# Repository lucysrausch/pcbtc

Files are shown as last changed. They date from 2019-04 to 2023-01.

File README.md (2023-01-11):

#PCB based MIDI Tesla Coil

For documentation, please see (and like ;) my Hackaday project: https://hackaday.io/project/165112-pcbtc-gan-edition

For the mainboard, please use V1.6 to order the pcbs. Select the pcb thickness to be as thin as possible, eg. 1mm.
For the current design you also need the bottom pcb coil (https://github.com/lucysrausch/pcbtc/tree/master/hardware/gerber_coil_01) and the top pcb coil (https://github.com/lucysrausch/pcbtc/tree/master/hardware/gerber_coil_04).
For these pcbs, please use 1.6mm thickness or thicker (eg. 2mm).

Check out the interactive html BOM for easier assembly: https://github.com/lucysrausch/pcbtc/blob/master/hardware/kicad/bom/ibom.html

Known bugs (V1.5):
* Missing pulldown for gatedriver input of the flyback converter
This can cause problems when in DFU mode as the mosfet might switch on permanently, shortying VUSB (Fixed in V1.6)
* Missing input decoupling capacitors underneath the LMG5200.
Adding additional high-quality 100pF and 100nF ceramic capacitors on the bottom of the pcb improves performance drastically (Fixed in V1.6)
* Unknown problem causes GaN module to fail when touching the arcs with the finger or a screwdriver.
The reson for this is unknown so far. Maybe EMI, maybe bad layout. Just don't touch the arcs for too long for now. Discharges to air work reliably. (Maybe fixed in V1.6 thanks to suggestions from nikisalli)

Flash with dfu-util -d 0483:df11 -a 0 -s 0x8000000:leave -D build/pcbtcMIDI.bin

Midi stack based on:
https://github.com/keshikan/CureMIDI 

## USB-MIDI Interface (2IN/2OUT) for STM32 "CureMIDI"

### Author

(c) 2018 Keshikan ( [Website](http://www.keshikan.net/),  [Twitter](https://twitter.com/keshinomi_88pro) )

### License

* USB MIDI Class Driver: [CC BY 4.0](https://creativecommons.org/licenses/by/4.0/)
* STM32 CubeF0: BSD-3-Clause based.
* Other Codes, Hardware, Schematic: [GPLv3](https://www.gnu.org/licenses/gpl-3.0.html)

See also [LICENSE.md](./LICENSE.md)

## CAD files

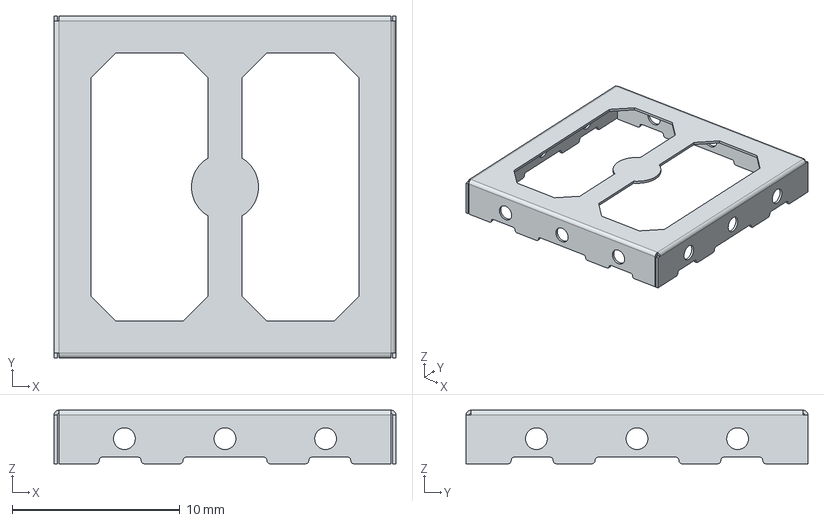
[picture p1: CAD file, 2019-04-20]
hardware/kicad/Download_STP_WE-SHC-36103205S (rev1).stp
20.4 x 20.4 x 3.20 mm

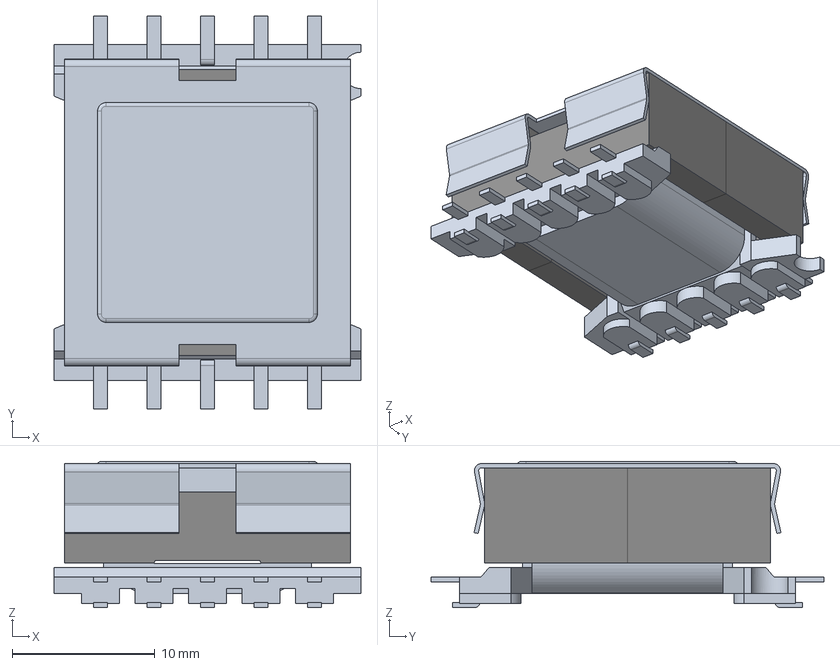
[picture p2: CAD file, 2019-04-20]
hardware/kicad/STEP-WE-FB-3751-EFD20-rev1.stp
21.5 x 27.5 x 10.2 mm

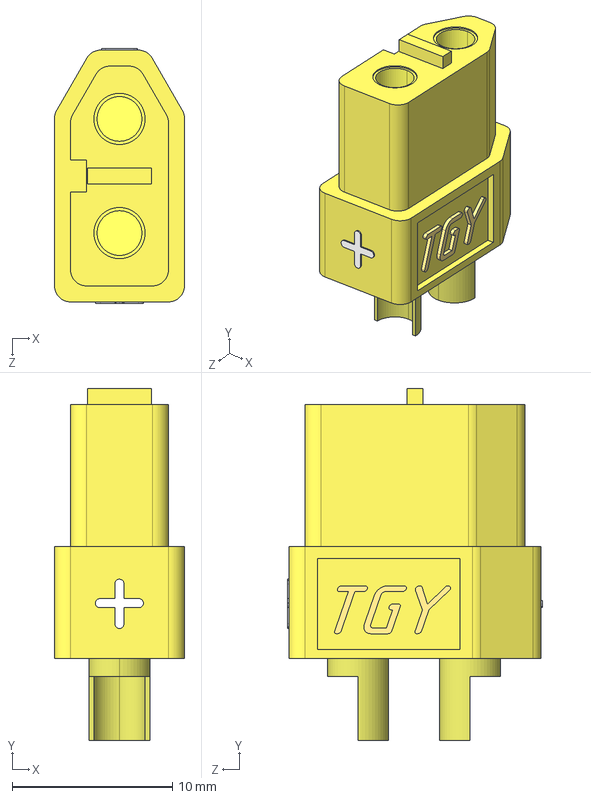
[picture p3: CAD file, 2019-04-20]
hardware/kicad/User Library-XT60.step
8.13 x 22.0 x 15.9 mm

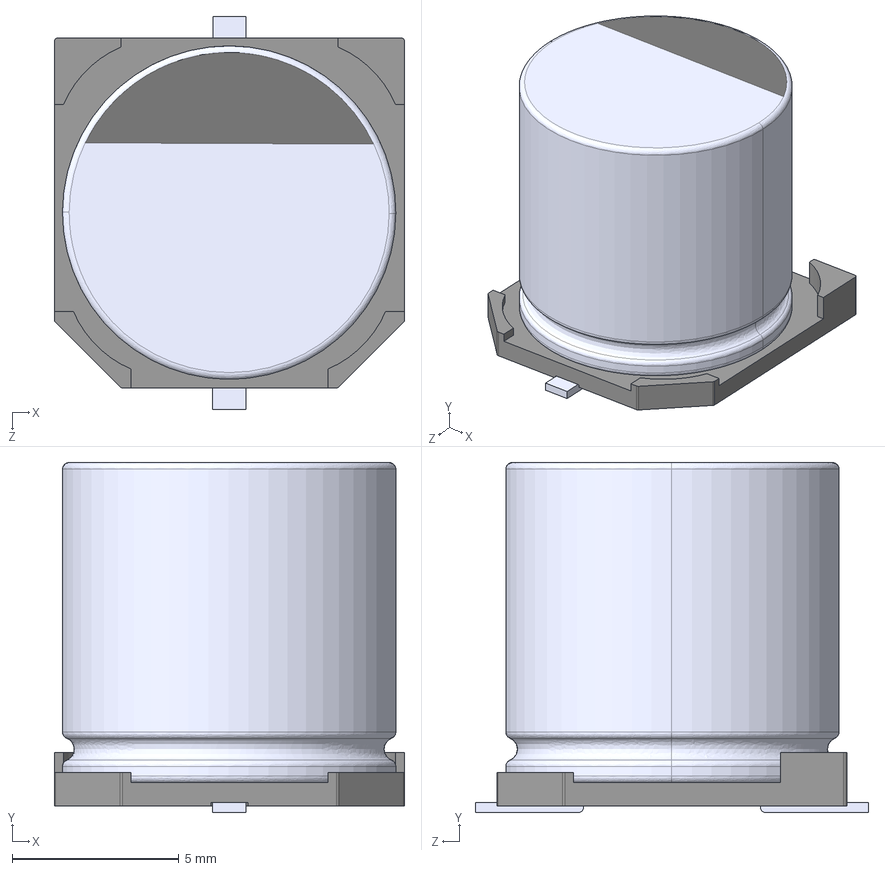
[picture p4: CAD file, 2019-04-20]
hardware/kicad/User Library-cap_10x10x10-1.STEP
10.5 x 10.5 x 11.8 mm
User Library-cap_10x10x10-1_can_10x10_1
User Library-cap_10x10x10-1_foot_cap_10x10_1 x 2
User Library-cap_10x10x10-1_alelcap_sm10x10_1

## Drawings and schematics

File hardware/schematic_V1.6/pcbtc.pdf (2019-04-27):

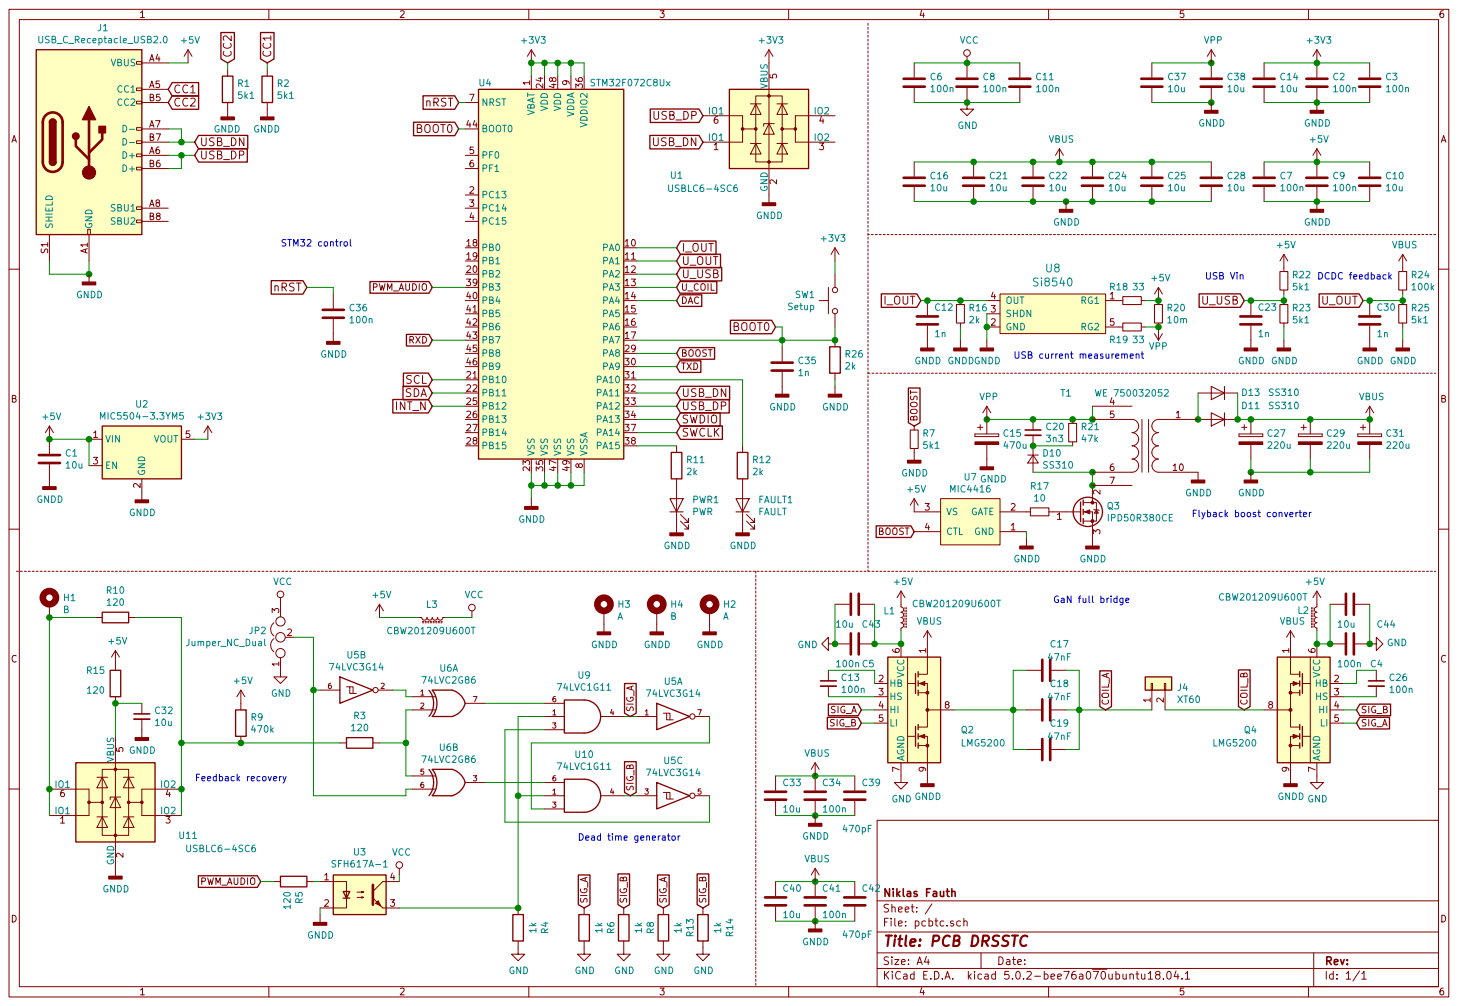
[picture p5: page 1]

9 VDDIO2 36 VSS 23 VSS 35 VSS 47 VSS 49 VSSA

2 EN 3 VOUT 5 U2 MIC5504-3.3YM5 +3V3 BOOST BOOST PWM_AUDIO

File: pcbtc.sch Sheet: / Niklas Fauth

Id: 1/1 Title: PCB DRSSTC

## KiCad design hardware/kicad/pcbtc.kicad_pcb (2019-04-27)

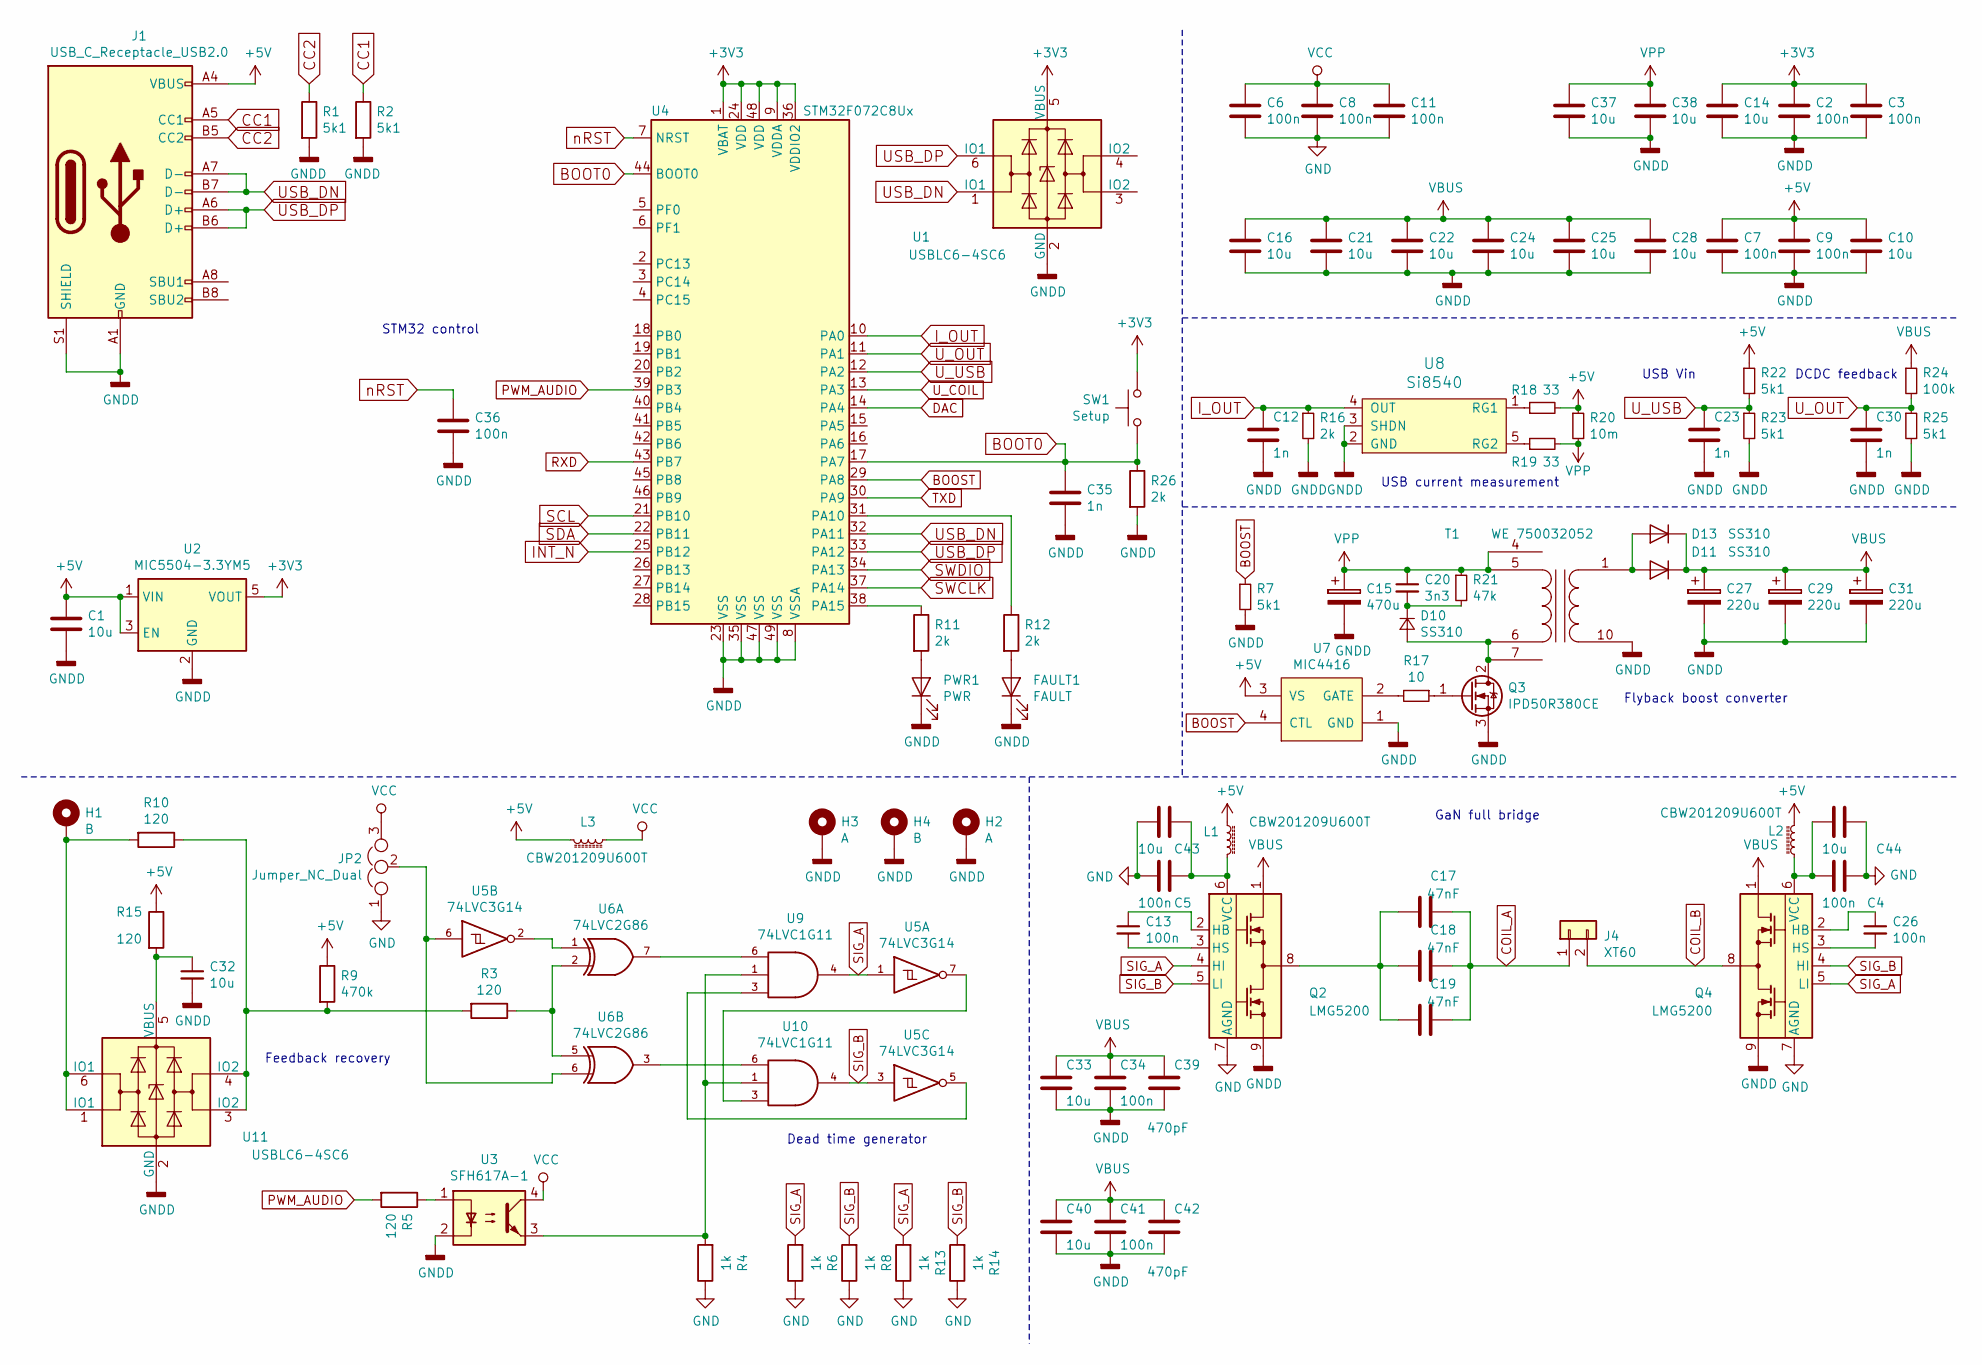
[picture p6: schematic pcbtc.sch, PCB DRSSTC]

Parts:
C1, C16, C21, C22, C24, C25, C28, C33, C37, C38, C40: 10u; C_1206_3216Metric
C2, C3, C4, C5, C6, C7, C8, C9, C11, C13, C26, C36: 100n; C_0603_1608Metric
C10, C14, C32, C43, C44: 10u; C_0603_1608Metric
C12, C23, C30, C35: 1n; C_0603_1608Metric
C15: 470u; C_Elec_10x10.2
C17, C18, C19: 47nF; C_Rect_L13.0mm_W6.5mm_P7.50mm_P10.00mm
C20: 3n3; C_1206_3216Metric
C27, C29, C31: 220u; C_Elec_10x10.2
C34, C41: 100n; C_1206_3216Metric
C39, C42: 470pF; C_1206_3216Metric
D10, D11, D13: SS310; D_SMA
FAULT1: FAULT; LED_0603_1608Metric
H1, H4: B; MountingHole_3.2mm_M3_Pad_Via
H2, H3: A; MountingHole_3.2mm_M3_Pad_Via
J1: USB_C_Receptacle_USB2.0; USB-C 16Pin
J4: XT60
JP2: Jumper_NC_Dual; SolderJumper-3_P1.3mm_Bridged12_RoundedPad1.0x1.5mm
L1, L2, L3: CBW201209U600T; L_0805_2012Metric
PWR1: PWR; LED_0603_1608Metric
Q2, Q4: LMG5200; Texas_MOF0009A
Q3: IPD50R380CE; TO-252-2
R1, R2: 5k1; C_0603_1608Metric
R3, R5, R10, R15: 120; R_0603_1608Metric
R4, R6, R8, R13, R14: 1k; R_0603_1608Metric
R7, R22, R23, R25: 5k1; R_0603_1608Metric
R9: 470k; R_0603_1608Metric
R11, R12, R16, R26: 2k; R_0603_1608Metric
R17: 10; R_0603_1608Metric
R18, R19: 33; R_0603_1608Metric
R20: 10m; R_1206_3216Metric
R21: 47k; R_1206_3216Metric
R24: 100k; R_0603_1608Metric
SW1: Setup; SW_SPST_EVQP7C
T1: WE 750032052; SignalCommunications-WE-FB3751_EFD20
U1, U11: USBLC6-4SC6; SOT-23-6
U2: MIC5504-3.3YM5; SOT-23-5
U3: SFH617A-1; DIP-4_W7.62mm_SMDSocket_SmallPads
U4: STM32F072C8Ux; QFN-48-1EP_7x7mm_P0.5mm_EP5.6x5.6mm
U5: 74LVC3G14; TSSOP-8_3x3mm_P0.65mm
U6: 74LVC2G86; TSSOP-8_3x3mm_P0.65mm
U7: MIC4416; SOT143-4P190_237X112L31X44N
U8: Si8540; SOT-23-5
U9, U10: 74LVC1G11; SOT-23-6

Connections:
+3V3: C2.1, C3.1, C14.1, SW1.1, U1.5 (VBUS), U2.5 (VOUT), U4.1 (VBAT), U4.9 (VDDA), U4.24 (VDD), U4.36 (VDDIO2), U4.48 (VDD)
+5V: C1.1, C7.1, C9.1, C10.1, J1.A4 (VBUS), J1.A9 (VBUS), J1.B4 (VBUS), J1.B9 (VBUS), L1.2, L2.2, L3.1, R9.1, R15.1, R18.2, R20.1, R22.1, U2.1 (VIN), U2.3 (EN), U7.3 (VS)
BOOST: R7.1, U4.29 (PA8), U7.4 (CTL)
BOOT0: C35.1, R26.1, SW1.2, U4.17 (PA7), U4.44 (BOOT0)
CC1: J1.A5 (CC1), R2.1
CC2: J1.B5 (CC2), R1.1
COIL_A: C17.1, C18.1, C19.1, J4.1
COIL_B: J4.2, Q4.8
DAC: U4.14 (PA4)
GND: C4.1, C5.2, C6.2, C8.2, C11.2, C43.2, C44.1, JP2.1, Q2.7 (AGND), Q4.7 (AGND), R4.1, R6.1, R8.1, R13.1, R14.1, U5.4 (GND), U6.4 (GND), U9.2 (GND), U10.2 (GND)
GNDD: C1.2, C2.2, C3.2, C7.2, C9.2, C10.2, C12.2, C14.2, C15.2, C16.2, C21.2, C22.2, C23.2, C24.2, C25.2, C27.2, C28.2, C29.2, C30.2, C31.2, C32.2, C33.2, C34.2, C35.2, C36.2, C37.2, C38.2, C39.2, C40.2, C41.2, C42.2, FAULT1.1 (K), H2.1, H3.1, H4.1, J1.A1 (GND), J1.A12 (GND), J1.B1 (GND), J1.B12 (GND), J1.S1 (SHIELD), PWR1.1 (K), Q2.9, Q3.3 (S), Q4.9, R1.2, R2.2, R7.2, R16.2, R23.2, R25.2, R26.2, T1.10 (SA), U1.2 (GND), U2.2 (GND), U3.2, U4.8 (VSSA), U4.23 (VSS), U4.35 (VSS), U4.47 (VSS), U4.49 (VSS), U7.1 (GND), U8.2 (GND), U8.3 (SHDN), U11.2 (GND)
INT_N: U4.25 (PB12)
I_OUT: C12.1, R16.1, U4.10 (PA0), U8.4 (OUT)
unnamed: C4.2, C44.2, L2.1, Q4.6 (VCC)
unnamed: C13.1, Q2.2 (HB)
unnamed: C13.2, Q2.3 (HS)
unnamed: C17.2, C18.2, C19.2, Q2.8
unnamed: C20.2, D10.1 (K), R21.2
unnamed: C26.1, Q4.2 (HB)
unnamed: C26.2, Q4.3 (HS)
unnamed: C32.1, R15.2, U11.5 (VBUS)
unnamed: C5.1, C43.1, L1.1, Q2.6 (VCC)
unnamed: D10.2 (A), Q3.2 (D), T1.6 (AB), T1.7
unnamed: D11.2 (A), D13.2 (A), T1.1 (SB)
unnamed: FAULT1.2 (A), R12.2
unnamed: H1.1, R10.2, U11.1 (IO1), U11.6 (IO1)
unnamed: JP2.2, U5.6, U6.6
unnamed: PWR1.2 (A), R11.2
unnamed: Q3.1 (G), R17.1
unnamed: R3.1, U6.2, U6.5
unnamed: R4.2, U3.3, U9.1, U10.1
unnamed: R5.1, U3.1
unnamed: R3.2, R9.2, R10.1, U11.3 (IO2), U11.4 (IO2)
unnamed: R11.1, U4.38 (PA15)
unnamed: R12.1, U4.31 (PA10)
unnamed: R17.2, U7.2 (GATE)
unnamed: R18.1, U8.1 (RG1)
unnamed: R19.1, U8.5 (RG2)
unnamed: U5.2, U6.1
unnamed: U5.5, U9.3
unnamed: U6.7, U9.6
unnamed: U5.7, U10.3
unnamed: U6.3, U10.6
PWM_AUDIO: R5.2, U4.39 (PB3)
RXD: U4.43 (PB7)
SCL: U4.21 (PB10)
SDA: U4.22 (PB11)
SIG_A: Q2.4 (HI), Q4.5 (LI), R6.2, R13.2, U5.1, U9.4
SIG_B: Q2.5 (LI), Q4.4 (HI), R8.2, R14.2, U5.3, U10.4
SWCLK: U4.37 (PA14)
SWDIO: U4.34 (PA13)
TXD: U4.30 (PA9)
USB_DN: J1.A7 (D-), J1.B7 (D-), U1.1 (IO1), U4.32 (PA11)
USB_DP: J1.A6 (D+), J1.B6 (D+), U1.6 (IO1), U4.33 (PA12)
U_COIL: U4.13 (PA3)
U_OUT: C30.1, R24.2, R25.1, U4.11 (PA1)
U_USB: C23.1, R22.2, R23.1, U4.12 (PA2)
VBUS: C16.1, C21.1, C22.1, C24.1, C25.1, C27.1, C28.1, C29.1, C31.1, C33.1, C34.1, C39.1, C40.1, C41.1, C42.1, D11.1 (K), D13.1 (K), Q2.1, Q4.1, R24.1
VCC: C6.1, C8.1, C11.1, JP2.3, L3.2, U3.4, U5.8 (VCC), U6.8 (VCC), U9.5 (VCC), U10.5 (VCC)
VPP: C15.1, C20.1, C37.1, C38.1, R19.2, R20.2, R21.1, T1.4, T1.5 (AA)
nRST: C36.1, U4.7 (NRST)

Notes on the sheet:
Feedback recovery
Dead time generator
GaN full bridge
Flyback boost converter
USB current measurement
DCDC feedback
USB Vin
STM32 control

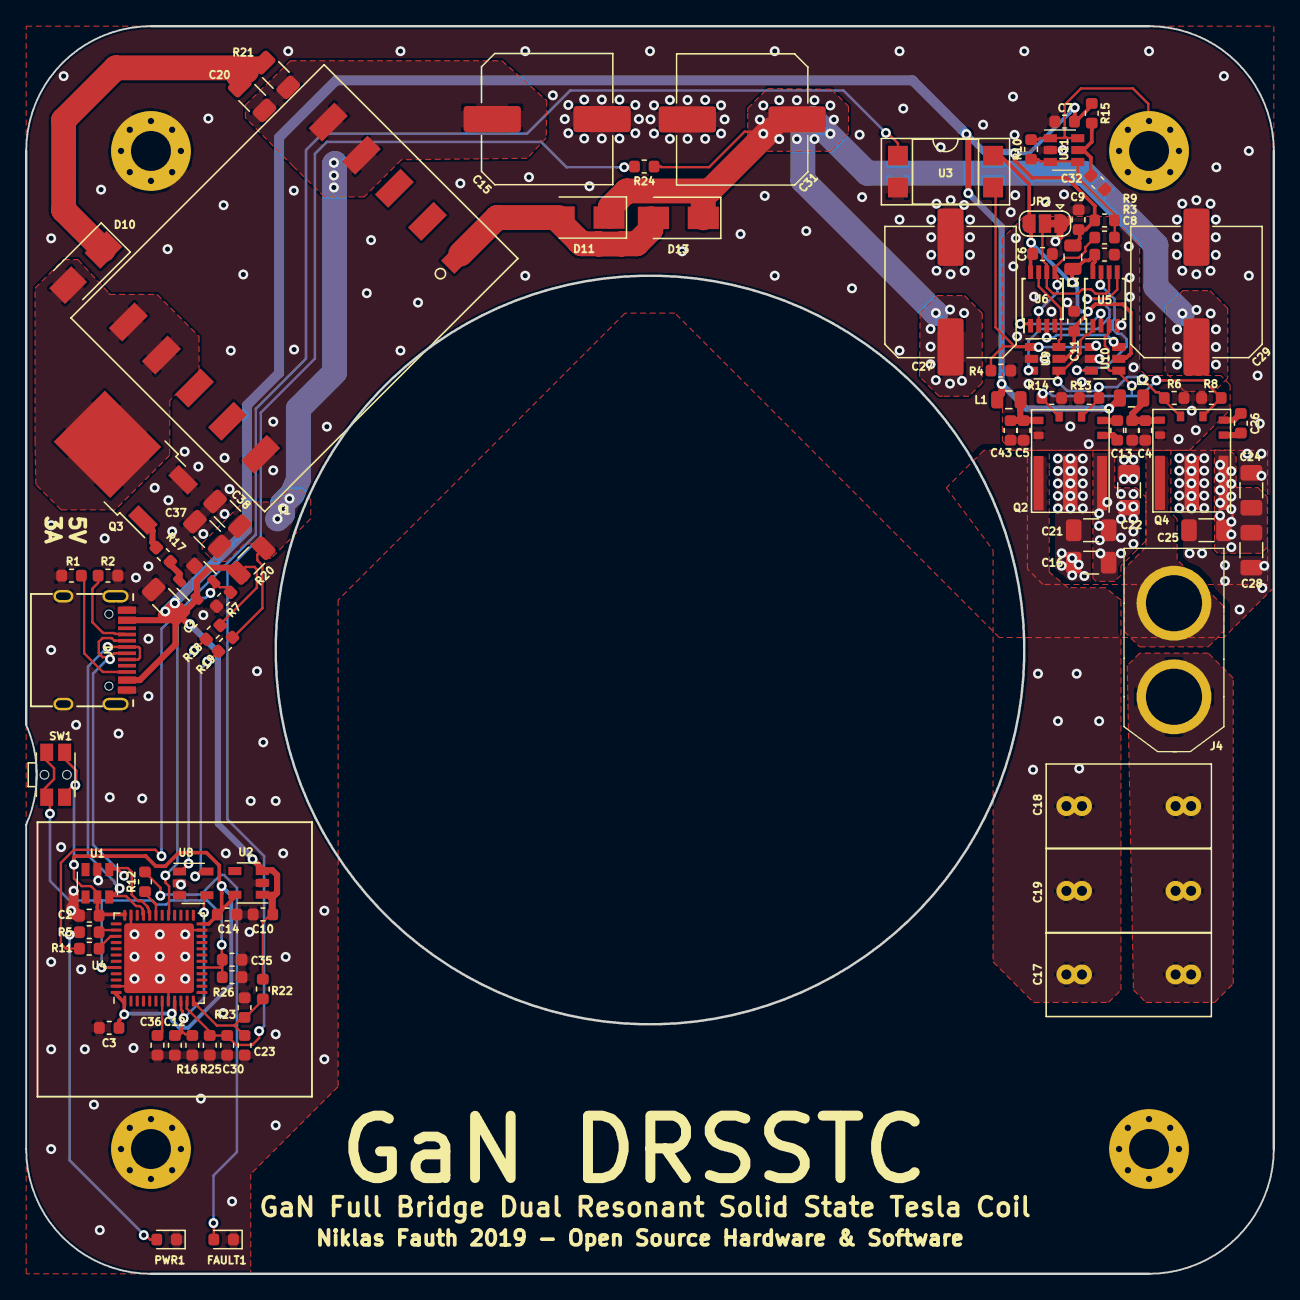
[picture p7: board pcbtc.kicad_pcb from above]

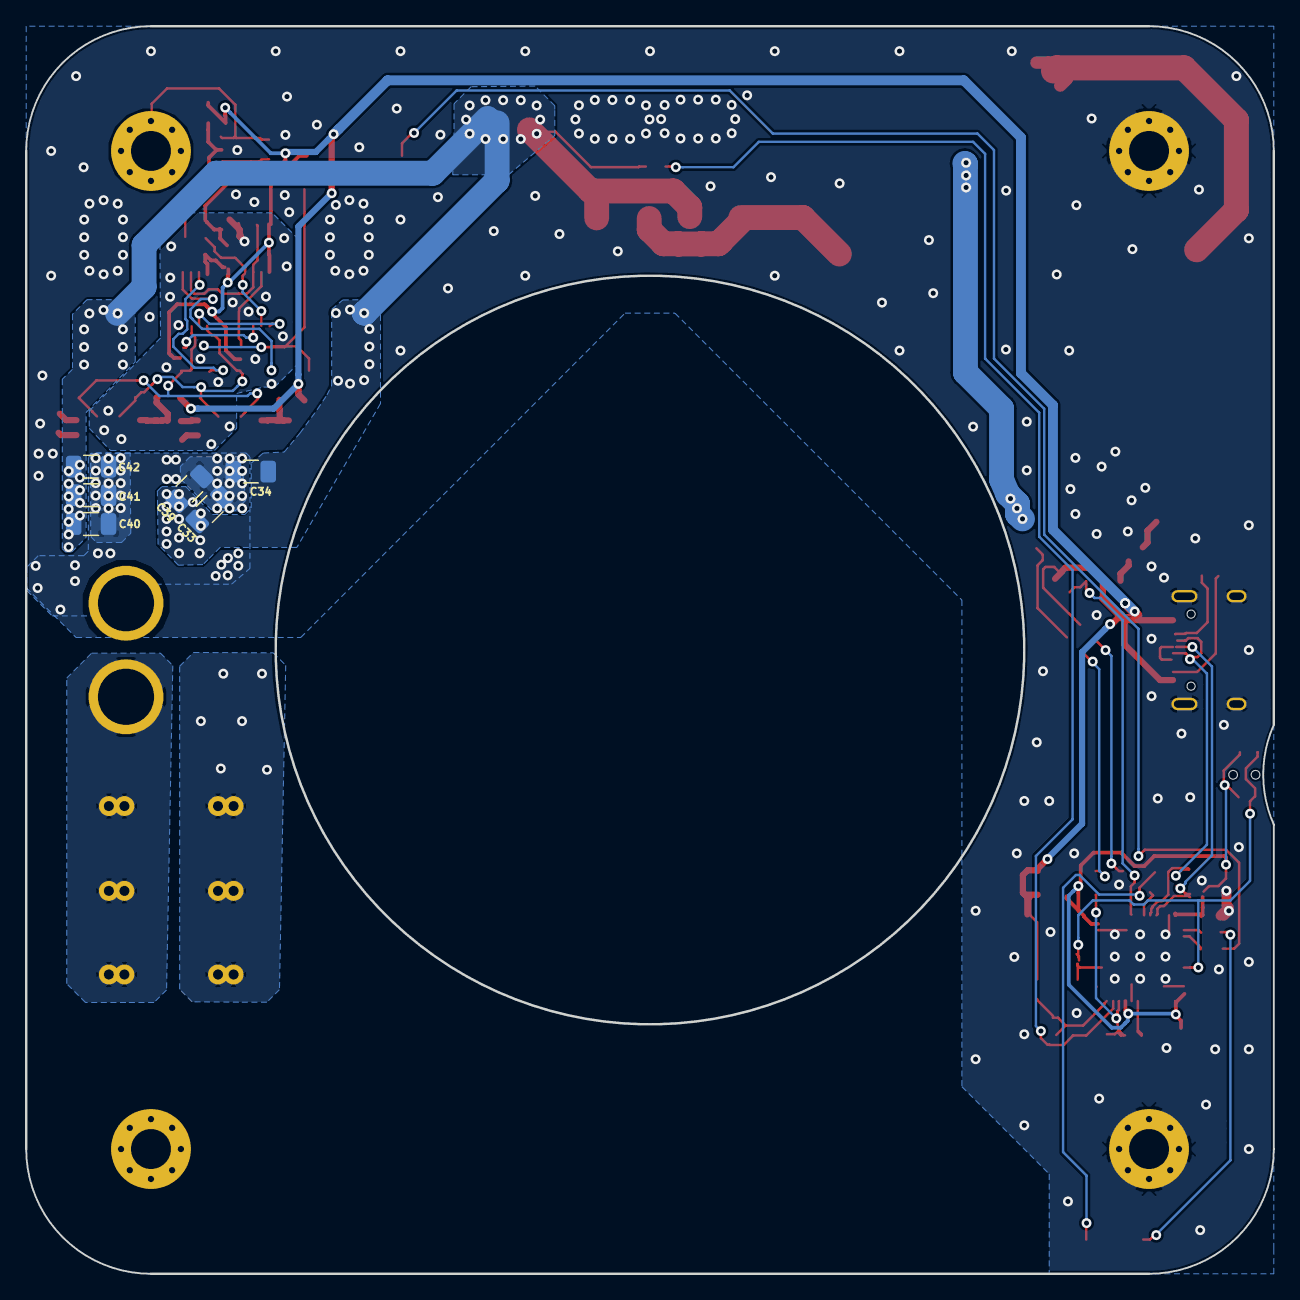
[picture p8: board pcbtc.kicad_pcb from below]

Board: 2 copper layers, 100.0 x 100.0 mm, 101 parts (6 on the bottom side), 52 nets.

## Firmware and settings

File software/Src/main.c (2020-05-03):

/**
  ******************************************************************************
  * @file           : main.c
  * @brief          : Main program body
  ******************************************************************************
  * This notice applies to any and all portions of this file
  * that are not between comment pairs USER CODE BEGIN and
  * USER CODE END. Other portions of this file, whether
  * inserted by the user or by software development tools
  * are owned by their respective copyright owners.
  *
  * Copyright (c) 2018 STMicroelectronics International N.V.
  * All rights reserved.
  *
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
  ******************************************************************************
  */
/* Includes ------------------------------------------------------------------*/
#include "main.h"
#include "stm32f0xx_hal.h"
#include "usb_device.h"

/* USER CODE BEGIN Includes */
#include "device_conf.h"
#include "curemisc.h"
#include "curebuffer.h"
#include "usbd_midi_if.h"
#include "math.h"

/* USER CODE END Includes */

TIM_HandleTypeDef htim14;
TIM_HandleTypeDef htim15;

TIM_HandleTypeDef htim17;

TIM_HandleTypeDef htim2;

TIM_HandleTypeDef htim1;

DAC_HandleTypeDef hdac;

ADC_HandleTypeDef hadc;
DMA_HandleTypeDef hdma_adc;

uint16_t adcBuffer[3];


uint8_t uart_tx_dat;
/* USER CODE END PV */

void SystemClock_Config(void);
static void MX_GPIO_Init(void);

static void MX_TIM14_Init(void);
static void MX_TIM15_Init(void);
static void MX_TIM17_Init(void);
static void USER_TIM2_Init(void);
static void USER_TIM1_Init(void);

static void MX_DAC_Init(void);

static void MX_DMA_Init(void);
static void MX_ADC_Init(void);

void htim17_update(void);

uint32_t Vout = 0;
uint16_t Iout = 0;
uint32_t Vset = 0;
uint32_t Vmax = 52000;

void htim17_update() {
  Iout = adcBuffer[0] * 1.33f;
  Vout = adcBuffer[1] * 16.6f;
  int32_t error = Vset - Vout;

  TIM1->CCR1 = CLAMP(error / 3, 0, 500);

  if (Vout > 55000) {
    TIM1->CCR1 = 0;
  }
}

/* USER CODE BEGIN PFP */
void dfu_otter_bootloader(void)
{
  *((unsigned long *)0x20003FF0) = 0xDEADBEEF;
  NVIC_SystemReset();
}
/* USER CODE END PFP */

/* USER CODE BEGIN 0 */

uint32_t curPeriode0 = 0;
uint32_t curPeriode1 = 0;

void HAL_TIM_PeriodElapsedCallback(TIM_HandleTypeDef *htim)
{
	if(htim->Instance == TIM14)
	{
		//HAL_TIM_OnePulse_Start(&htim2, TIM_CHANNEL_2);
    if (TIM2->CNT == 0) {
      TIM2->ARR = (uint32_t)(curPeriode0 / CLAMP(((Iout/200)-10), 3, 16)); // Play first channel
    	TIM2->CR1 = TIM2->CR1 | 1;
    }
	}
	if(htim->Instance == TIM15)
	{
		//HAL_TIM_OnePulse_Start(&htim2, TIM_CHANNEL_2);
    if (TIM2->CNT == 0) {
    	TIM2->ARR = (uint32_t)(curPeriode1 / 8); // Play second channel with less power
    	TIM2->CR1 = TIM2->CR1 | 1;
    }
	}
}

/**
  * @brief  The application entry point.
  *
  * @retval None
  */


uint8_t midiBuffer[4];
uint8_t midiState = 0;

uint16_t curTone0 = 0;
uint16_t curTone1 = 0;
uint16_t curChannel = 0;
uint16_t lastTone0 = 0;
uint16_t lastTone1 = 0;
uint32_t noteTimeout = 0;

uint16_t freqs[16] = {0};


int main(void)
{
  /* MCU Configuration----------------------------------------------------------*/

  /* Reset of all peripherals, Initializes the Flash interface and the Systick. */
  HAL_Init();

  /* Configure the system clock */
  SystemClock_Config();

  /* Initialize all configured peripherals */
  MX_GPIO_Init();
  HAL_GPIO_WritePin(LED_POW_GPIO, LED_POW_PIN, SET);
  HAL_GPIO_WritePin(LED_FAULT_GPIO, LED_FAULT_PIN, SET);

	MX_DAC_Init();

	HAL_DAC_Start(&hdac, DAC_CHANNEL_1);
	HAL_DAC_SetValue(&hdac, DAC_CHANNEL_1, DAC_ALIGN_12B_R, 2048);

	MX_TIM14_Init();
	HAL_TIM_Base_Start_IT(&htim14);
	TIM14->CR1 &= ~(1UL);

	MX_TIM15_Init();
	HAL_TIM_Base_Start_IT(&htim15);
	TIM15->CR1 &= ~(1UL);

  MX_DMA_Init();
  MX_ADC_Init();

  HAL_ADC_Start_DMA(&hadc, (uint32_t*)adcBuffer, 3);


	USER_TIM1_Init();

  //HAL_TIM_PWM_Start(&htim1);
  HAL_TIM_PWM_Start_IT(&htim1, TIM_CHANNEL_1);

  //__HAL_TIM_SET_COMPARE(&htim1, TIM_CHANNEL_1, 1000);

  USER_TIM2_Init();

	HAL_TIM_Base_Start(&htim2);
	HAL_TIM_OnePulse_Start(&htim2, TIM_CHANNEL_2);

  /* USER CODE BEGIN 2 */

  //USB-MIDI Init
  MX_USB_MIDI_INIT();

  //HAL_GPIO_WritePin(LED_POW_GPIO, LED_POW_PIN, RESET);


  if(FUNC_ERROR == midiInit() ){
	  while(1){
		  HAL_GPIO_WritePin(LED_POW_GPIO, LED_POW_PIN, SET);
		  HAL_Delay(500);
		  HAL_GPIO_WritePin(LED_POW_GPIO, LED_POW_PIN, RESET);
		  HAL_Delay(500);
	  }
  }

  //Wait usb configuration.
  while(1){
	  if(USBD_STATE_CONFIGURED == hUsbDeviceFS.dev_state){
		  //HAL_GPIO_WritePin(LED_POW_GPIO, LED_POW_PIN, SET);
		  break;
	  }else{
		  HAL_GPIO_WritePin(LED_POW_GPIO, LED_POW_PIN, RESET);
	  }
  }

  MX_TIM17_Init();
	HAL_TIM_Base_Start_IT(&htim17);

  for (uint32_t i = 0; i < Vmax; i+=100) {
    Vset = i;
    HAL_Delay(3);
  }

  HAL_GPIO_WritePin(LED_FAULT_GPIO, LED_FAULT_PIN, RESET);

  Vset = Vmax;

  while (1)
  {
  //Wait USB configuration when USB connection error has occurred.
	   while(1){
				//HAL_GPIO_WritePin(LED_POW_GPIO, LED_POW_PIN, SET);
			if(USBD_STATE_CONFIGURED == hUsbDeviceFS.dev_state){
			  HAL_GPIO_WritePin(LED_POW_GPIO, LED_POW_PIN, SET);
			  break;
		  }else{
			  HAL_GPIO_WritePin(LED_POW_GPIO, LED_POW_PIN, SET);
			  HAL_Delay(200);
			  HAL_GPIO_WritePin(LED_POW_GPIO, LED_POW_PIN, RESET);
			  HAL_Delay(200);
		  }
	  }
    if (HAL_GPIO_ReadPin(BUTTON_GPIO, BUTTON_PIN)) {
      dfu_otter_bootloader();
    }


		curTone0 = 0;
		curTone1 = 0;

	  for( int i = 0; i < 16; i++ ) { // find max pitch from all channels
	      if( freqs[i] > curTone0 ) {
	          curTone1 = curTone0;
	          curTone0 = freqs[i];
	      }
	      else if( freqs[i] > curTone1 ) {
	          curTone1 = freqs[i];
	      }
	  }

		if (curTone0 > 20 && curTone0 != lastTone0) { // play one tone using TIM14
			curPeriode0 = (uint32_t)1000000 / (uint32_t)(curTone0);
			TIM14->CNT = 0;
			TIM14->ARR = curPeriode0;
			TIM14->CR1 = TIM14->CR1 | 1;
			lastTone0 = curTone0;
			noteTimeout = HAL_GetTick();

			HAL_GPIO_WritePin(LED_FAULT_GPIO, LED_FAULT_PIN, SET);
		} else if (curTone0 < 20 && curTone0 != lastTone0) {
			TIM14->CR1 &= ~(1UL);
      curPeriode0 = 0;

			HAL_GPIO_WritePin(LED_FAULT_GPIO, LED_FAULT_PIN, RESET);
		}

		if (curTone1 > 20 && curTone1 != lastTone1) { // play other polyphonic tone ussing TIM15
			curPeriode1 = (uint32_t)1000000 / (uint32_t)(curTone1);
			TIM15->CNT = 0;
			TIM15->ARR = curPeriode1;
			TIM15->CR1 = TIM15->CR1 | 1;
			lastTone1 = curTone1;
			noteTimeout = HAL_GetTick();
		} else if (curTone1 < 20 && curTone1 != lastTone1) {
			TIM15->CR1 &= ~(1UL);
      curPeriode1 = 0;
		}

		if ((HAL_GetTick() - noteTimeout) > 1000) {
			TIM14->CR1 &= ~(1UL);
			TIM15->CR1 &= ~(1UL);
			for (int i = 0; i < 16; i++) {
				freqs[i] = 0;
			}

			HAL_GPIO_WritePin(LED_FAULT_GPIO, LED_FAULT_PIN, RESET);
		}


		//[USB-MIDI IN] to [MIDI JACK OUT]

		if( FUNC_SUCCESS == midiGetFromUsbRx(0, &uart_tx_dat)){
			if (uart_tx_dat >> 7 == 1) {
				midiBuffer[0] = uart_tx_dat;
				midiBuffer[1] = 0;
				midiBuffer[2] = 0;
				midiState = 1;
			} else if (midiState == 1) {
				midiBuffer[1] = uart_tx_dat;
				midiState = 2;
			} else if (midiState == 2) {
				midiBuffer[2] = uart_tx_dat;
				midiState = 3;

				if ((midiBuffer[0] & 0xF0) == 0x90) { // Note on, 2 data bytes
					char key = midiBuffer[1];
					char vel = midiBuffer[2];

					uint16_t freq = pow(2,(key-0x45)/12.0)*440.0;

					curChannel = midiBuffer[0] & 0xF;

					// Note on with a velocity of 0x00 is the same as a note off message. MIDI Spec: 
					// "A receiver must be capable of recognizing either method of turning off a note, and should treat them identically."
					if (vel == 0) {
						if (freqs[curChannel] == freq)
							freqs[curChannel] = 0;
					} else {
						freqs[curChannel] = freq;
					}
					
				}

				if ((midiBuffer[0] & 0xF0) == 0x80) { // Note off, 2 data bytes
					char key = midiBuffer[1];
					char vel = midiBuffer[2];

					uint16_t freq = pow(2,(key-0x45)/12.0)*440.0;

					//if (freqs[midiBuffer[0] & 0xF] == freq) {
					freqs[midiBuffer[0] & 0xF] = 0;
					//}
				}
			}
		}

	//[MIDI JACK IN] to [USB-MIDI OUT]
	//midiProcess();


  }
  /* USER CODE END 3 */

}

/** System Clock Configuration
*/
void SystemClock_Config(void)
{

  RCC_OscInitTypeDef RCC_OscInitStruct;
  RCC_ClkInitTypeDef RCC_ClkInitStruct;
  RCC_PeriphCLKInitTypeDef PeriphClkInit;

    /**Initializes the CPU, AHB and APB busses clocks
    */
  RCC_OscInitStruct.OscillatorType = RCC_OSCILLATORTYPE_HSI14|RCC_OSCILLATORTYPE_HSI48;
  RCC_OscInitStruct.HSI48State = RCC_HSI48_ON;
  RCC_OscInitStruct.HSI14State = RCC_HSI14_ON;
  RCC_OscInitStruct.HSI14CalibrationValue = 16;
  RCC_OscInitStruct.PLL.PLLState = RCC_PLL_NONE;
  if (HAL_RCC_OscConfig(&RCC_OscInitStruct) != HAL_OK)
  {
    _Error_Handler(__FILE__, __LINE__);
  }

    /**Initializes the CPU, AHB and APB busses clocks
    */
  RCC_ClkInitStruct.ClockType = RCC_CLOCKTYPE_HCLK|RCC_CLOCKTYPE_SYSCLK
                              |RCC_CLOCKTYPE_PCLK1;
  RCC_ClkInitStruct.SYSCLKSource = RCC_SYSCLKSOURCE_HSI48;
  RCC_ClkInitStruct.AHBCLKDivider = RCC_SYSCLK_DIV1;
  RCC_ClkInitStruct.APB1CLKDivider = RCC_HCLK_DIV1;

  if (HAL_RCC_ClockConfig(&RCC_ClkInitStruct, FLASH_LATENCY_1) != HAL_OK)
  {
    _Error_Handler(__FILE__, __LINE__);
  }

  PeriphClkInit.PeriphClockSelection = RCC_PERIPHCLK_USB;
  PeriphClkInit.UsbClockSelection = RCC_USBCLKSOURCE_HSI48;

  if (HAL_RCCEx_PeriphCLKConfig(&PeriphClkInit) != HAL_OK)
  {
    _Error_Handler(__FILE__, __LINE__);
  }

    /**Configure the Systick interrupt time
    */
  HAL_SYSTICK_Config(HAL_RCC_GetHCLKFreq()/1000);

    /**Configure the Systick
    */
  HAL_SYSTICK_CLKSourceConfig(SYSTICK_CLKSOURCE_HCLK);

  /* SysTick_IRQn interrupt configuration */
  HAL_NVIC_SetPriority(SysTick_IRQn, 0, 0);
}

/* ADC init function */
static void MX_ADC_Init(void)
{
  __HAL_RCC_ADC1_CLK_ENABLE();
  ADC_ChannelConfTypeDef sConfig;

    /**Configure the global features of the ADC (Clock, Resolution, Data Alignment and number of conversion)
    */
  hadc.Instance = ADC1;
  hadc.Init.ClockPrescaler = ADC_CLOCK_ASYNC_DIV1;
  hadc.Init.Resolution = ADC_RESOLUTION_12B;
  hadc.Init.DataAlign = ADC_DATAALIGN_RIGHT;
  hadc.Init.ScanConvMode = ADC_SCAN_DIRECTION_FORWARD;
  hadc.Init.EOCSelection = ADC_EOC_SEQ_CONV;
  hadc.Init.LowPowerAutoWait = DISABLE;
  hadc.Init.LowPowerAutoPowerOff = DISABLE;
  hadc.Init.ContinuousConvMode = DISABLE;
  hadc.Init.DiscontinuousConvMode = DISABLE;
  hadc.Init.ExternalTrigConv = ADC_EXTERNALTRIGCONV_T1_TRGO;
  hadc.Init.ExternalTrigConvEdge = ADC_EXTERNALTRIGCONVEDGE_RISING;
  hadc.Init.DMAContinuousRequests = ENABLE;
  hadc.Init.Overrun = ADC_OVR_DATA_PRESERVED;
  if (HAL_ADC_Init(&hadc) != HAL_OK)
  {
    _Error_Handler(__FILE__, __LINE__);
  }

    /**Configure for the selected ADC regular channel to be converted.
    */
  sConfig.Channel = ADC_CHANNEL_0;
  sConfig.Rank = ADC_RANK_CHANNEL_NUMBER;
  sConfig.SamplingTime = ADC_SAMPLETIME_28CYCLES_5;
  if (HAL_ADC_ConfigChannel(&hadc, &sConfig) != HAL_OK)
  {
    _Error_Handler(__FILE__, __LINE__);
  }

    /**Configure for the selected ADC regular channel to be converted.
    */
  sConfig.Channel = ADC_CHANNEL_1;
  if (HAL_ADC_ConfigChannel(&hadc, &sConfig) != HAL_OK)
  {
    _Error_Handler(__FILE__, __LINE__);
  }

    /**Configure for the selected ADC regular channel to be converted.
    */
  sConfig.Channel = ADC_CHANNEL_2;
  if (HAL_ADC_ConfigChannel(&hadc, &sConfig) != HAL_OK)
  {
    _Error_Handler(__FILE__, __LINE__);
  }


}

/**
  * Enable DMA controller clock
  */
static void MX_DMA_Init(void)
{
  /* DMA controller clock enable */
  __HAL_RCC_DMA1_CLK_ENABLE();

  /* DMA interrupt init */
  /* DMA1_Channel1_IRQn interrupt configuration */
  HAL_NVIC_SetPriority(DMA1_Channel1_IRQn, 0, 0);
  HAL_NVIC_EnableIRQ(DMA1_Channel1_IRQn);

}


/* TIM14 init function */
static void MX_TIM14_Init(void)
{
  htim14.Instance = TIM14;
  htim14.Init.Prescaler = 11;
  htim14.Init.CounterMode = TIM_COUNTERMODE_UP;
  htim14.Init.Period = 1000;
  htim14.Init.ClockDivision = TIM_CLOCKDIVISION_DIV4;
  htim14.Init.RepetitionCounter = 0;
  htim14.Init.AutoReloadPreload = TIM_AUTORELOAD_PRELOAD_DISABLE;
  if (HAL_TIM_Base_Init(&htim14) != HAL_OK)
  {
    _Error_Handler(__FILE__, __LINE__);
  }
}

/* TIM15 init function */
static void MX_TIM15_Init(void)
{
  htim15.Instance = TIM15;
  htim15.Init.Prescaler = 11;
  htim15.Init.CounterMode = TIM_COUNTERMODE_UP;
  htim15.Init.Period = 1000;
  htim15.Init.ClockDivision = TIM_CLOCKDIVISION_DIV4;
  htim15.Init.RepetitionCounter = 0;
  htim15.Init.AutoReloadPreload = TIM_AUTORELOAD_PRELOAD_DISABLE;
  if (HAL_TIM_Base_Init(&htim15) != HAL_OK)
  {
    _Error_Handler(__FILE__, __LINE__);
  }
}

/* TIM17 init function */
static void MX_TIM17_Init(void)
{
  htim17.Instance = TIM17;
  htim17.Init.Prescaler = 11;
  htim17.Init.CounterMode = TIM_COUNTERMODE_UP;
  htim17.Init.Period = 1000;
  htim17.Init.ClockDivision = TIM_CLOCKDIVISION_DIV4;
  htim17.Init.RepetitionCounter = 0;
  htim17.Init.AutoReloadPreload = TIM_AUTORELOAD_PRELOAD_ENABLE;
  if (HAL_TIM_Base_Init(&htim17) != HAL_OK)
  {
    _Error_Handler(__FILE__, __LINE__);
  }
}

static void USER_TIM2_Init(void) {
	__HAL_RCC_TIM2_CLK_ENABLE();

	TIM_ClockConfigTypeDef sClockSourceConfig;
	TIM_MasterConfigTypeDef sMasterConfig;
	TIM_OC_InitTypeDef sConfigOC;

	htim2.Instance = TIM2;
	htim2.Init.Prescaler = 0;
	htim2.Init.CounterMode = TIM_COUNTERMODE_UP;
	htim2.Init.Period = 3200;
	htim2.Init.ClockDivision = TIM_CLOCKDIVISION_DIV4;
	HAL_TIM_Base_Init(&htim2);

	sMasterConfig.MasterOutputTrigger = TIM_TRGO_RESET;
	sMasterConfig.MasterSlaveMode = TIM_MASTERSLAVEMODE_DISABLE;
	HAL_TIMEx_MasterConfigSynchronization(&htim2, &sMasterConfig);

	sConfigOC.OCMode = TIM_OCMODE_PWM1;
	sConfigOC.Pulse = 1;
	sConfigOC.OCPolarity = TIM_OCPOLARITY_LOW;
	sConfigOC.OCFastMode = TIM_OCFAST_DISABLE;
	HAL_TIM_PWM_ConfigChannel(&htim2, &sConfigOC, TIM_CHANNEL_2);

	HAL_TIM_OnePulse_Init(&htim2, TIM_OPMODE_SINGLE);
	HAL_TIM_MspPostInit(&htim2);
}

static void USER_TIM1_Init(void)
{
  __HAL_RCC_TIM1_CLK_ENABLE();

  TIM_MasterConfigTypeDef sMasterConfig;
  TIM_OC_InitTypeDef sConfigOC;
  TIM_BreakDeadTimeConfigTypeDef sBreakDeadTimeConfig;

  htim1.Instance = TIM1;
  htim1.Init.Prescaler = 0;
  htim1.Init.CounterMode = TIM_COUNTERMODE_UP;
  htim1.Init.Period = 1024;
  htim1.Init.ClockDivision = TIM_CLOCKDIVISION_DIV2;
  htim1.Init.RepetitionCounter = 0;
  htim1.Init.AutoReloadPreload = TIM_AUTORELOAD_PRELOAD_ENABLE;
  if (HAL_TIM_PWM_Init(&htim1) != HAL_OK)
  {
    _Error_Handler(__FILE__, __LINE__);
  }

  sMasterConfig.MasterOutputTrigger = TIM_TRGO_UPDATE;
  sMasterConfig.MasterSlaveMode = TIM_MASTERSLAVEMODE_DISABLE;
  if (HAL_TIMEx_MasterConfigSynchronization(&htim1, &sMasterConfig) != HAL_OK)
  {
    _Error_Handler(__FILE__, __LINE__);
  }

  sConfigOC.OCMode = TIM_OCMODE_PWM1;
  sConfigOC.Pulse = 0;
  sConfigOC.OCPolarity = TIM_OCPOLARITY_HIGH;
  sConfigOC.OCNPolarity = TIM_OCNPOLARITY_HIGH;
  sConfigOC.OCFastMode = TIM_OCFAST_DISABLE;
  sConfigOC.OCIdleState = TIM_OCIDLESTATE_RESET;
  sConfigOC.OCNIdleState = TIM_OCNIDLESTATE_RESET;
  if (HAL_TIM_PWM_ConfigChannel(&htim1, &sConfigOC, TIM_CHANNEL_1) != HAL_OK)
  {
    _Error_Handler(__FILE__, __LINE__);
  }

  sBreakDeadTimeConfig.OffStateRunMode = TIM_OSSR_DISABLE;
  sBreakDeadTimeConfig.OffStateIDLEMode = TIM_OSSI_DISABLE;
  sBreakDeadTimeConfig.LockLevel = TIM_LOCKLEVEL_OFF;
  sBreakDeadTimeConfig.DeadTime = 0;
  sBreakDeadTimeConfig.BreakState = TIM_BREAK_DISABLE;
  sBreakDeadTimeConfig.BreakPolarity = TIM_BREAKPOLARITY_HIGH;
  sBreakDeadTimeConfig.AutomaticOutput = TIM_AUTOMATICOUTPUT_DISABLE;
  if (HAL_TIMEx_ConfigBreakDeadTime(&htim1, &sBreakDeadTimeConfig) != HAL_OK)
  {
    _Error_Handler(__FILE__, __LINE__);
  }

  HAL_TIM_MspPostInit(&htim1);
}


/* DAC init function */
static void MX_DAC_Init(void)
{

  DAC_ChannelConfTypeDef sConfig;

    /**DAC Initialization
    */
  hdac.Instance = DAC;
  if (HAL_DAC_Init(&hdac) != HAL_OK)
  {
    _Error_Handler(__FILE__, __LINE__);
  }

    /**DAC channel OUT1 config
    */
  sConfig.DAC_Trigger = DAC_TRIGGER_NONE;
  sConfig.DAC_OutputBuffer = DAC_OUTPUTBUFFER_ENABLE;
  if (HAL_DAC_ConfigChannel(&hdac, &sConfig, DAC_CHANNEL_1) != HAL_OK)
  {
    _Error_Handler(__FILE__, __LINE__);
  }

}



/**
  * Enable DMA controller clock
  */


/** Configure pins as
        * Analog
        * Input
        * Output
        * EVENT_OUT
        * EXTI
*/
static void MX_GPIO_Init(void)
{

  GPIO_InitTypeDef GPIO_InitStruct;

  /* GPIO Ports Clock Enable */
  __HAL_RCC_GPIOF_CLK_ENABLE();
  __HAL_RCC_GPIOA_CLK_ENABLE();
  __HAL_RCC_GPIOB_CLK_ENABLE();

  /*Configure GPIO pin Output Level */
  HAL_GPIO_WritePin(GPIOA, GPIO_PIN_10|GPIO_PIN_15, GPIO_PIN_RESET);

  /*Configure GPIO pins : PA4 PA5 PA6 PA7 */
  GPIO_InitStruct.Pin = GPIO_PIN_10|GPIO_PIN_15;
  GPIO_InitStruct.Mode = GPIO_MODE_OUTPUT_PP;
  GPIO_InitStruct.Pull = GPIO_NOPULL;
  GPIO_InitStruct.Speed = GPIO_SPEED_FREQ_LOW;
  HAL_GPIO_Init(GPIOA, &GPIO_InitStruct);
}

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


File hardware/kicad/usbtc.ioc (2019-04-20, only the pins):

Mcu.UserName=STM32F072C8Ux
PA0.Signal=GPIO_Input
PA1.Signal=ADC_IN1
PA10.Signal=GPIO_Output
PA11.Signal=USB_DM
PA12.Signal=USB_DP
PA13.Signal=SYS_SWDIO
PA14.Signal=SYS_SWCLK
PA15.Signal=GPIO_Output
PA2.Signal=ADC_IN2
PA3.Signal=ADC_IN3
PA4.Signal=COMP_DAC1_group
PA5.Signal=COMP_DAC2_group
PA8.Signal=S_TIM1_CH1
PA9.Signal=USART1_TX
PB3.Signal=S_TIM2_CH2
PB7.Signal=USART1_RX

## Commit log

2018-07-08 Modified readme. Updated schematic.
2018-12-02 woriking with single timer 2 in OC mode
    [CureMIDI_IF Debug.cfg]
2018-12-02 pcbtc: Initial commit
2018-12-21 UPD: schematics
2018-12-21 ADD: schematics
    [pcbtc.sch]
2019-04-13 V1.2 wroking release
    [altium_coil_01.PcbDoc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]
2019-04-20 ADD: schematics and kicad project
    [Download_STP_WE-SHC-36103205S (rev1).stp, STEP-WE-FB-3751-EFD20-rev1.stp, User Library-XT60.step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]
2019-04-22 pretty schematics
    [pcbtc.sch]
2019-04-27 Released V1.6 gerber
    [pcbtc-B.Cu.gbl, pcbtc-B.Mask.gbs, pcbtc-B.Paste.gbp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]
2019-04-27 FIX: interactive html bom capacitor values
    [pcbtc-B.Cu.gbl, pcbtc-B.Mask.gbs, pcbtc-B.Paste.gbp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]
2020-05-03 Fix handling of zero velocity note on messages
    [main.c]

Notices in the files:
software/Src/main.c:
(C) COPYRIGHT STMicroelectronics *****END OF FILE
